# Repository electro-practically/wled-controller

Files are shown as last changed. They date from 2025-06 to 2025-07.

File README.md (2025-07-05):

# WLED Controller

**WLED Controller** is a compact, **single-sided PCB** designed to run WLED firmware and control **two addressable LED strips**. It is powered entirely via **USB-C Power-Delivery** and supports either **5V or 12V** LED strips, with a maximum power of **60W**. Compatible with popular LED types such as **WS2812B** (5V) and **WS2815** (12V). It offers a clean, efficient solution for custom lighting projects.

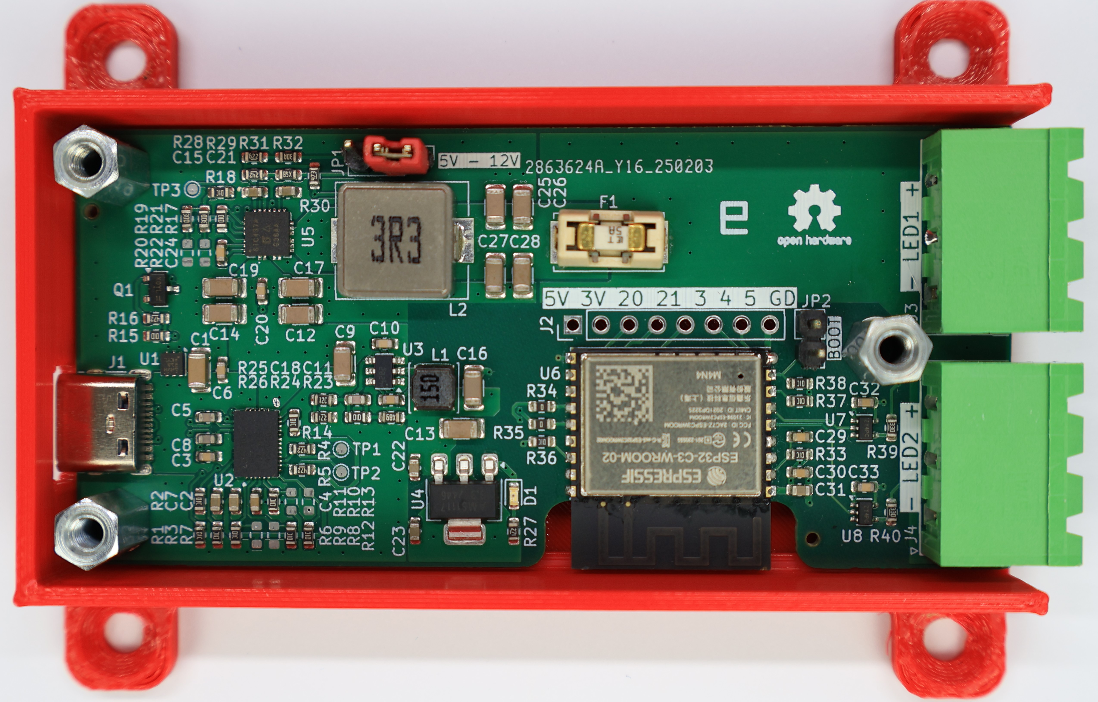
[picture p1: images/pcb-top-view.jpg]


## Block diagram



The entire board is powered via the USB-C connector. Voltage and current levels are negotiated through the TPS25730D USB Power Delivery (PD) controller, based on onboard configuration resistors. The supported input range is 5–20 V and 0.5–5 A, and the controller always negotiates the highest available voltage profile supported by the connected power adapter. These voltage/current profiles can be customized by soldering different resistor values.

There are two power paths:

1. **LED Power Path**: supplies power to the LED strips. The input voltage is stepped down by a SiC437 buck converter, providing high-efficiency regulation tailored to the selected LED voltage (5 V or 12 V). This path is protected by a fuse.

2. **Logic Power Path**: supplies power to the ESP32 and other low-power components. This path uses a TPS54202 buck converter to generate a stable 5 V rail, which is further regulated down to 3.3 V using an AMS1117 low-dropout (LDO) regulator.

A dedicated ENABLE signal from the ESP32 is used to control the LED power converter (SiC437). When LEDs are turned off in WLED, this signal disables the converter entirely - removing the need for additional output relays or transistors typically used to disconnect LED power.

The USB-C connector also provides a direct connection to the ESP32 via the USB 2.0, allowing firmware flashing and debug access without additional interfaces.

## PCB description

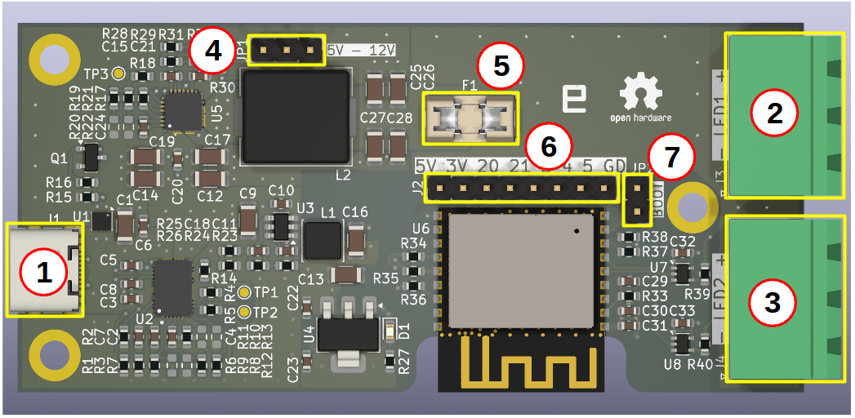
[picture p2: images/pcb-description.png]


1. **USB-C connector.** Used for flashing the WLED firmware onto the ESP32 and for powering the entire board—including connected LED strips—via the USB Power Delivery (PD) protocol. Ensure you use a high-quality USB-C cable capable of handling the required current.
2. **LED output 1.** Connector for the first LED strip, providing power (+/-) and data signals.
3. **LED output 2.** Connector for the second LED strip, providing power (+/-) and data signals.
4. **LED voltage selector.** This 3-pin jumper is used to select the output voltage for the connected LED strips - either 5V or 12V. Always short the center pin with either the 5V or 12V pin, depending on your required LED strip voltage. Be careful, if no jumper is installed, the output voltage will be extremely low (close to 0V), and the LED strips will not function properly.
5. **Protection fuse.** Protects the board from short circuits or faults originating from the connected LED strips.
6. **GPIOs.** These exposed GPIO pins can be configured in WLED to support a variety of additional functions beyond basic LED control, including buttons, I2S microphone, IR receiver etc. Pin description:
    1. +5V
    2. +3.3V
    3. GPIO20
    4. GPIO21
    5. GPIO3
    6. GPIO4
    7. GPIO5
    8. GND
7. **Boot jumper.** Used to place the ESP32 into bootloader mode for firmware flashing.

## Bring-up guide

Follow these steps to flash the WLED firmware and configure the board:

1. Set the LED voltage jumper (5 V or 12 V) according to your connected LED strips.
2. Place a jumper on the BOOT connector to put the ESP32 into bootloader mode.
3. Connect the board to your PC using a USB-C cable.
4. Once connected, remove the BOOT jumper.
5. Install the WLED firmware following the official instructions: [kno.wled.ge](https://kno.wled.ge/basics/getting-started/)
6. Configure WLED as follows (see LED Preferences settings category in the web UI):
    1. **LED1 Data GPIO**: 7
    2. **LED2 Data GPIO**: 6
    3. **Relay GPIO**: 10 (no invert, no open drain)
7. Disconnect the USB from your PC and connect a suitable power adapter via USB-C.
8. Setup complete - the board is ready to use.

## Thermal consideration

If you power a long LED strip with relatively high power consumption, it may be necessary to provide heat dissipation for the controller - for example, using an aluminum case or a case with a fan. Most of the heat is dissipated by the SiC437 buck converter.

## Input power source type

The controller was tested with a standard USB power brick used for phone charging with USB Power Delivery capability. However, it should also work with other USB-C devices that support Power Delivery in source mode - for example, power banks, monitors, laptops, and similar devices. If you plan to power the controller from such a source, ensure that it supports the required USB PD power profile.

## License

[CERN Open Hardware Licence Version 2 - Permissive](https://cern-ohl.web.cern.ch/home)

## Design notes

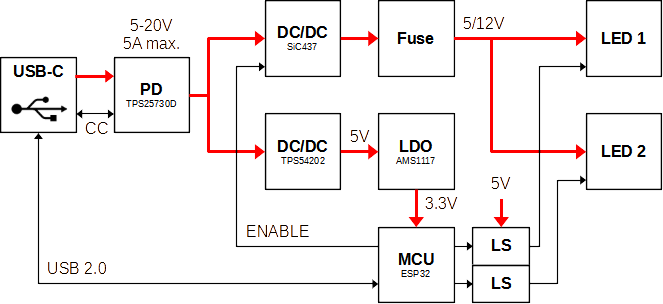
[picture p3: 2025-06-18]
images/block-diagram.png

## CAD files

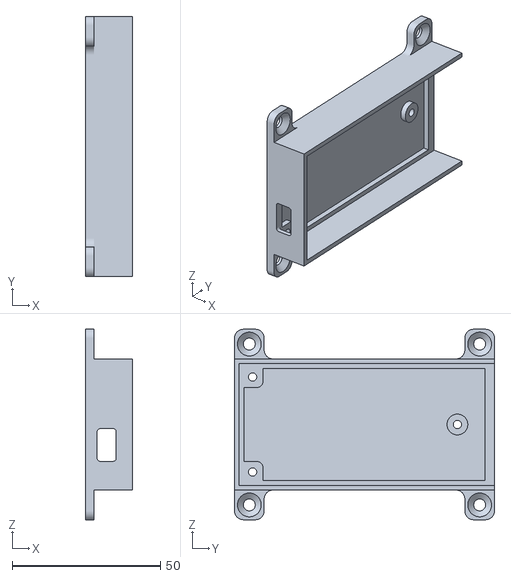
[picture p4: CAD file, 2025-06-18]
case/wled-controller-Bottom.stl
16.0 x 87.6 x 64.2

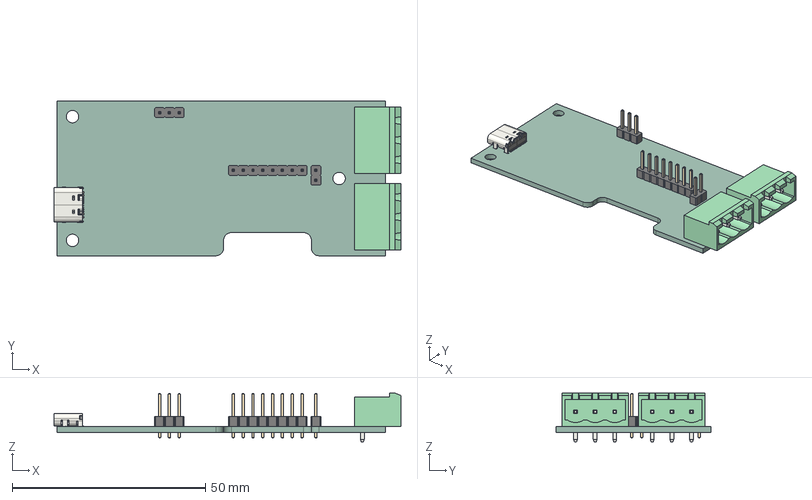
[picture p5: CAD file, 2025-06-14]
pcb/wled-controller.step
89.8 x 40.0 x 12.6 mm
PinHeader_1x03_P2.54mm_Vertical
PinHeader_1x08_P2.54mm_Vertical
PhoenixContact_MSTBA_2,5_3-G-5,08_1x03_P5.08mm_Horizontal x 2
USB_C_Receptacle_GCT_USB4105-xx-A_16P_TopMnt_Horizontal
PinHeader_1x02_P2.54mm_Vertical
wled-controller_PCB

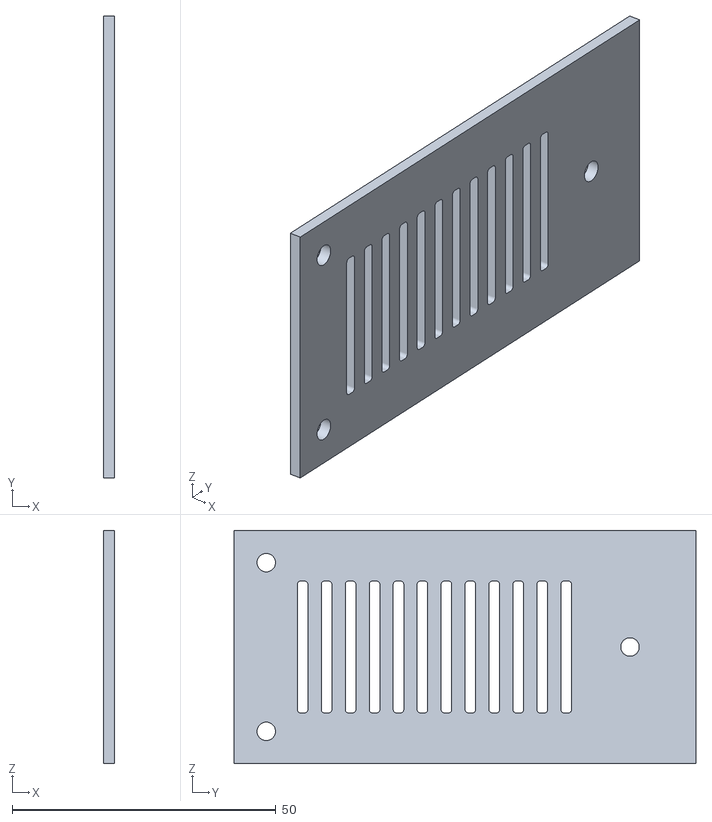
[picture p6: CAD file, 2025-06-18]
case/wled-controller-Top.stl
2.00 x 87.6 x 44.2

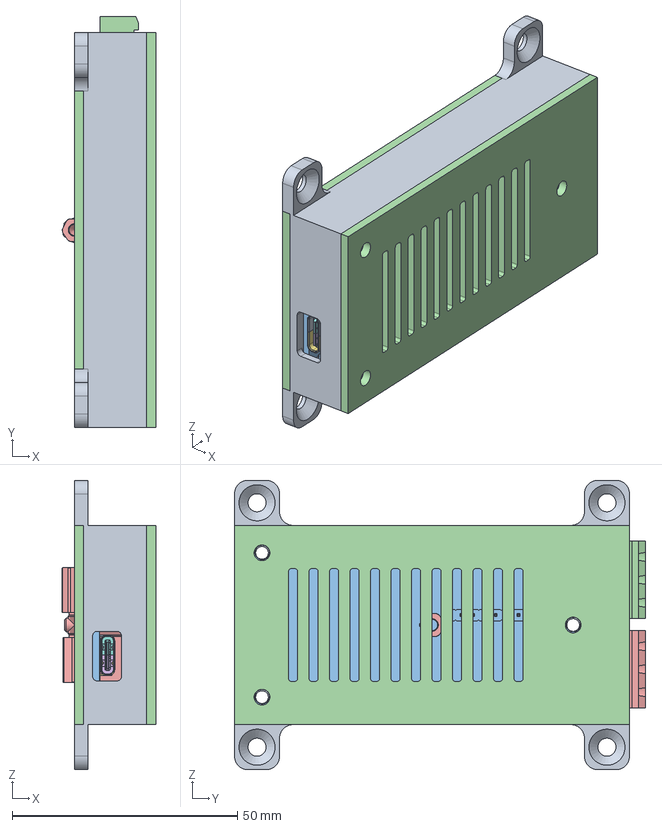
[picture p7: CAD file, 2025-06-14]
case/wled-controller.FCStd
20.7 x 91.1 x 64.2 mm
Bottom x 2
PinHeader_1x03_P2.54mm_Vertical
PinHeader_1x08_P2.54mm_Vertical
PhoenixContact_MSTBA_2,5_3-G-5,08_1x03_P5.08mm_Horizontal
PhoenixContact_MSTBA_2,5_3-G-5,08_1x03_P5.08mm_Horizontal001
USB_C_Receptacle_GCT_USB4105-xx-A_16P_TopMnt_Horizontal
USB_C_Receptacle_GCT_USB4105-xx-A_16P_TopMnt_Horizontal001
USB_C_Receptacle_GCT_USB4105-xx-A_16P_TopMnt_Horizontal002
USB_C_Receptacle_GCT_USB4105-xx-A_16P_TopMnt_Horizontal003
USB_C_Receptacle_GCT_USB4105-xx-A_16P_TopMnt_Horizontal004
USB_C_Receptacle_GCT_USB4105-xx-A_16P_TopMnt_Horizontal005
USB_C_Receptacle_GCT_USB4105-xx-A_16P_TopMnt_Horizontal006
USB_C_Receptacle_GCT_USB4105-xx-A_16P_TopMnt_Horizontal007
USB_C_Receptacle_GCT_USB4105-xx-A_16P_TopMnt_Horizontal008
USB_C_Receptacle_GCT_USB4105-xx-A_16P_TopMnt_Horizontal009
USB_C_Receptacle_GCT_USB4105-xx-A_16P_TopMnt_Horizontal010
USB_C_Receptacle_GCT_USB4105-xx-A_16P_TopMnt_Horizontal011
USB_C_Receptacle_GCT_USB4105-xx-A_16P_TopMnt_Horizontal012
USB_C_Receptacle_GCT_USB4105-xx-A_16P_TopMnt_Horizontal013
USB_C_Receptacle_GCT_USB4105-xx-A_16P_TopMnt_Horizontal014
USB_C_Receptacle_GCT_USB4105-xx-A_16P_TopMnt_Horizontal015
USB_C_Receptacle_GCT_USB4105-xx-A_16P_TopMnt_Horizontal016
USB_C_Receptacle_GCT_USB4105-xx-A_16P_TopMnt_Horizontal017
USB_C_Receptacle_GCT_USB4105-xx-A_16P_TopMnt_Horizontal018
USB_C_Receptacle_GCT_USB4105-xx-A_16P_TopMnt_Horizontal019
USB_C_Receptacle_GCT_USB4105-xx-A_16P_TopMnt_Horizontal020
USB_C_Receptacle_GCT_USB4105-xx-A_16P_TopMnt_Horizontal021
USB_C_Receptacle_GCT_USB4105-xx-A_16P_TopMnt_Horizontal022
USB_C_Receptacle_GCT_USB4105-xx-A_16P_TopMnt_Horizontal023
USB_C_Receptacle_GCT_USB4105-xx-A_16P_TopMnt_Horizontal024
USB_C_Receptacle_GCT_USB4105-xx-A_16P_TopMnt_Horizontal025
USB_C_Receptacle_GCT_USB4105-xx-A_16P_TopMnt_Horizontal026
USB_C_Receptacle_GCT_USB4105-xx-A_16P_TopMnt_Horizontal027
USB_C_Receptacle_GCT_USB4105-xx-A_16P_TopMnt_Horizontal028
USB_C_Receptacle_GCT_USB4105-xx-A_16P_TopMnt_Horizontal029
USB_C_Receptacle_GCT_USB4105-xx-A_16P_TopMnt_Horizontal030
USB_C_Receptacle_GCT_USB4105-xx-A_16P_TopMnt_Horizontal031
USB_C_Receptacle_GCT_USB4105-xx-A_16P_TopMnt_Horizontal032
USB_C_Receptacle_GCT_USB4105-xx-A_16P_TopMnt_Horizontal033
USB_C_Receptacle_GCT_USB4105-xx-A_16P_TopMnt_Horizontal034
USB_C_Receptacle_GCT_USB4105-xx-A_16P_TopMnt_Horizontal035
PinHeader_1x02_P2.54mm_Vertical
wled-controller_PCB
Top x 2
M3x10x5-Standoff x 3

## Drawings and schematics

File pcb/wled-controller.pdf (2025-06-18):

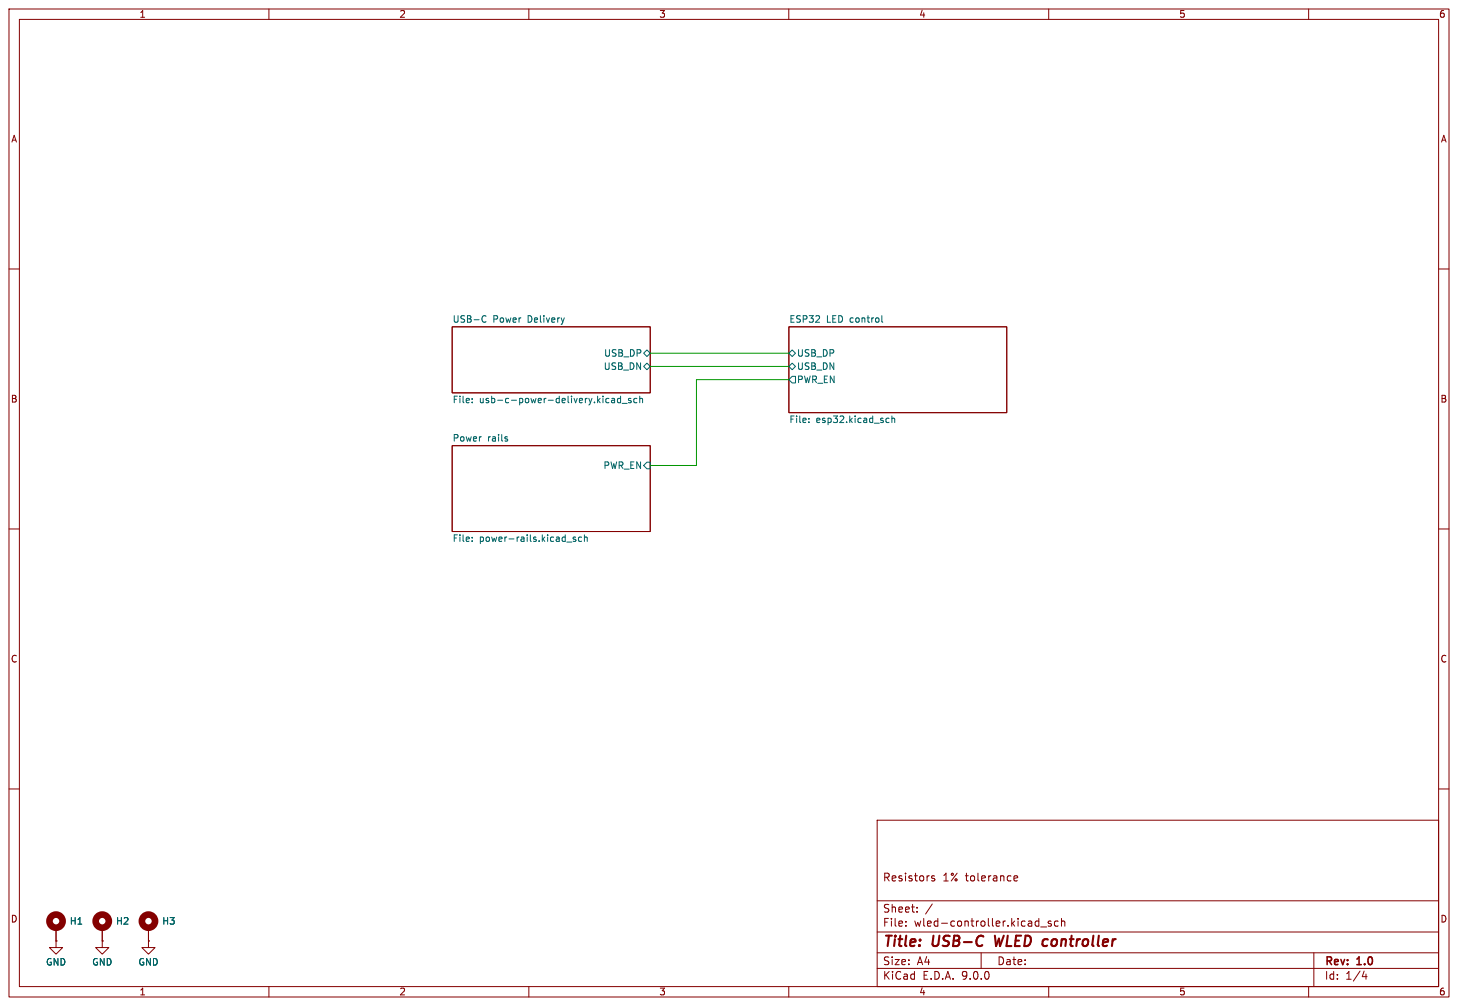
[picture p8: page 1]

Id: 1/4 Title: USB-C WLED controller File: wled-controller.kicad_sch Sheet: / Resistors 1% tolerance PWR_EN

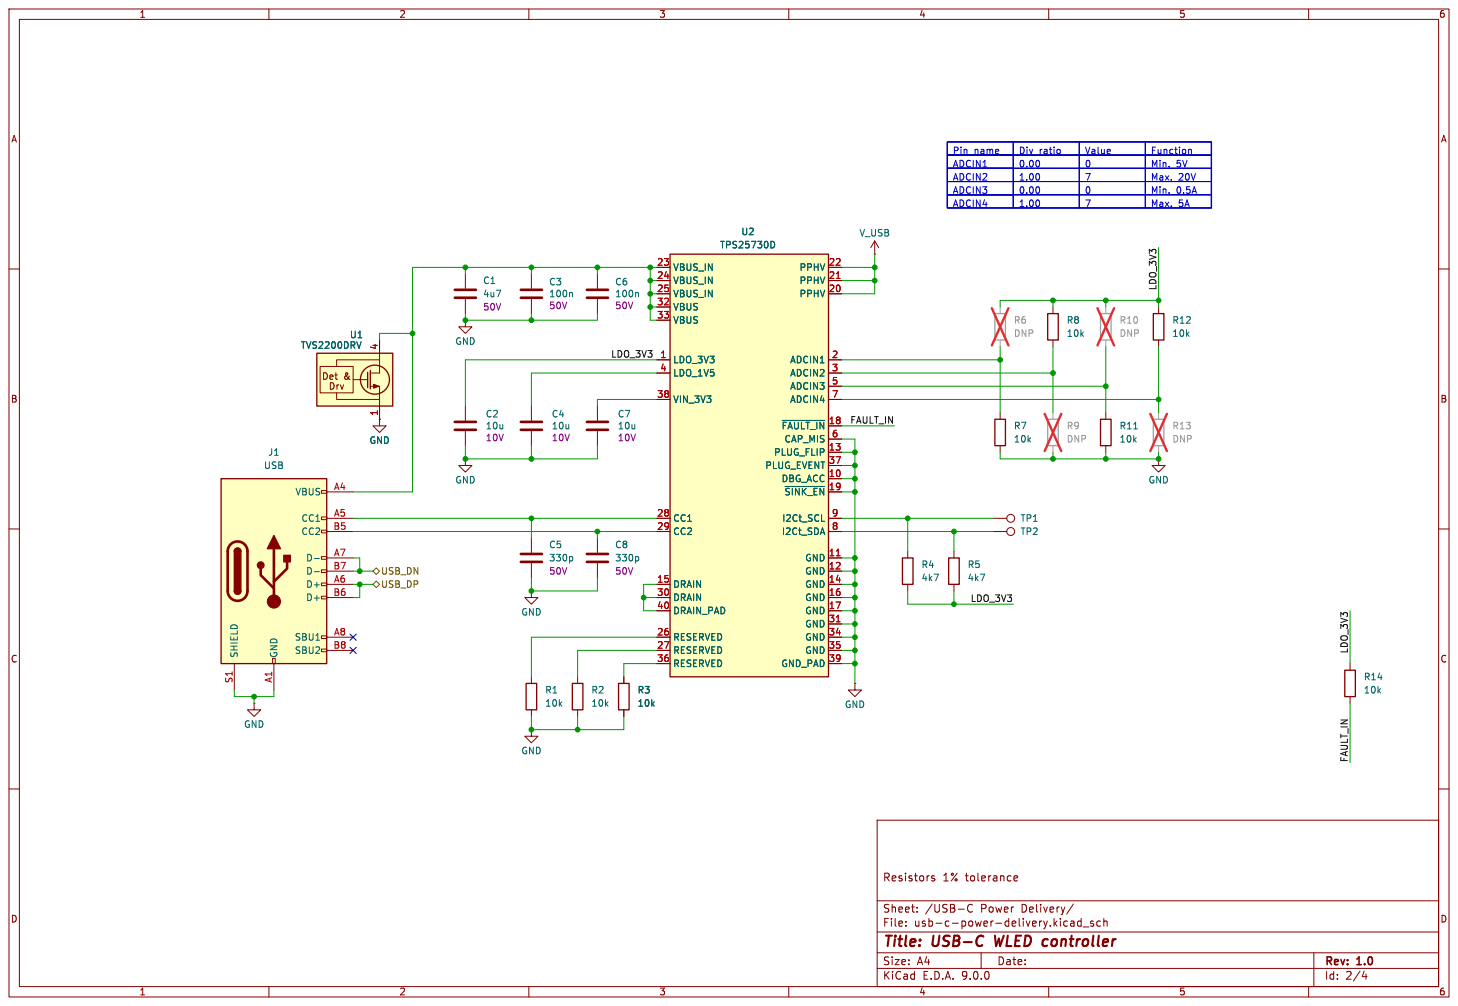
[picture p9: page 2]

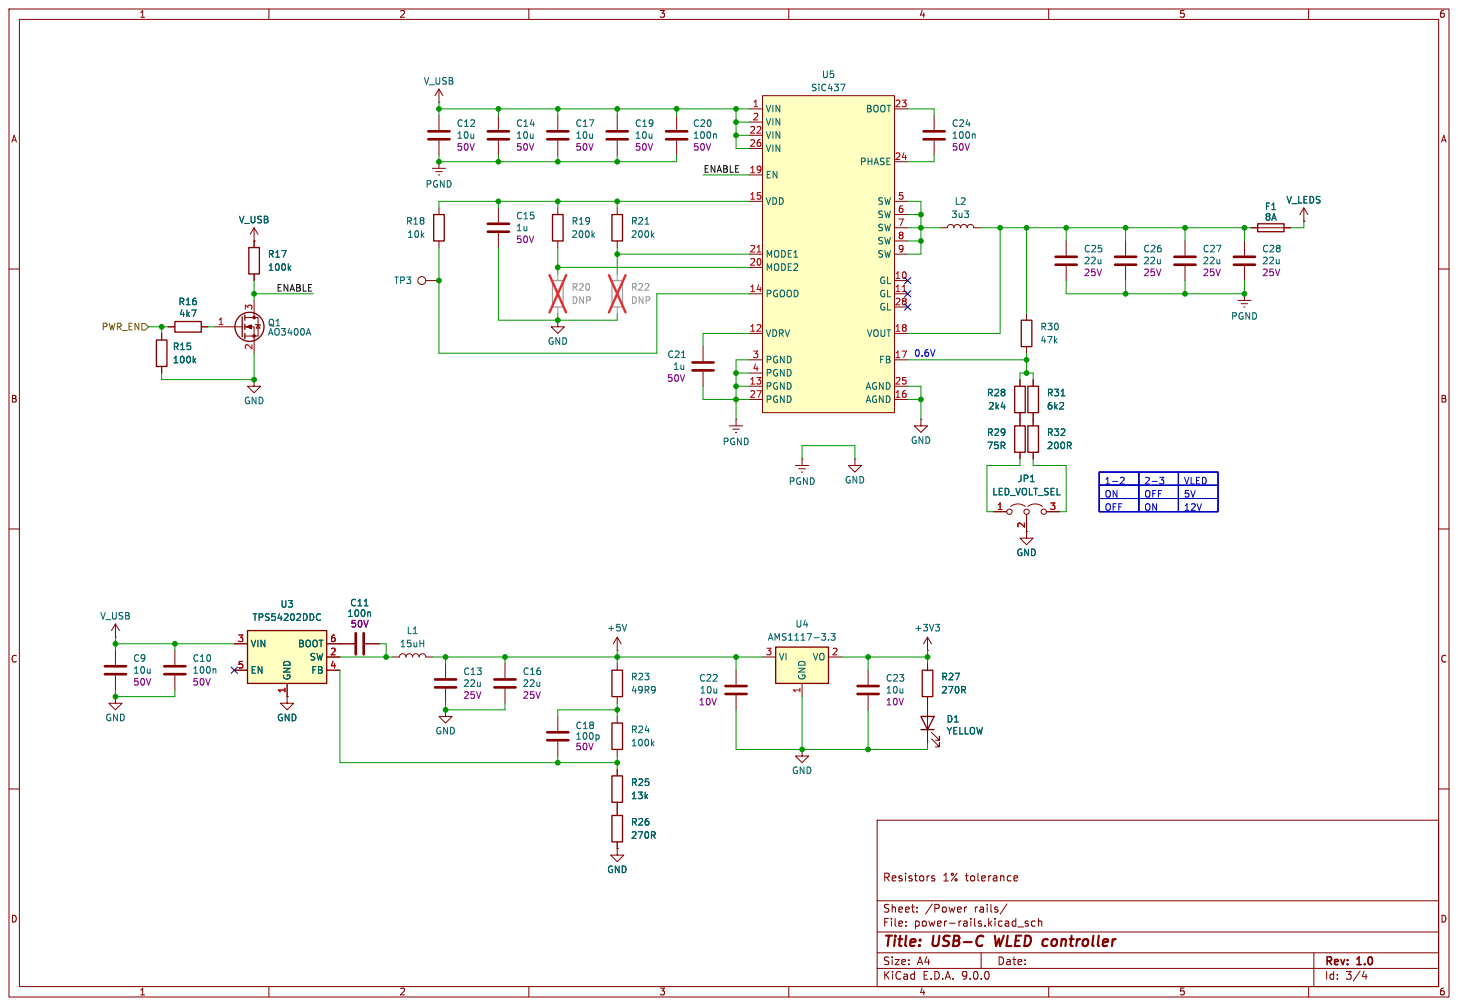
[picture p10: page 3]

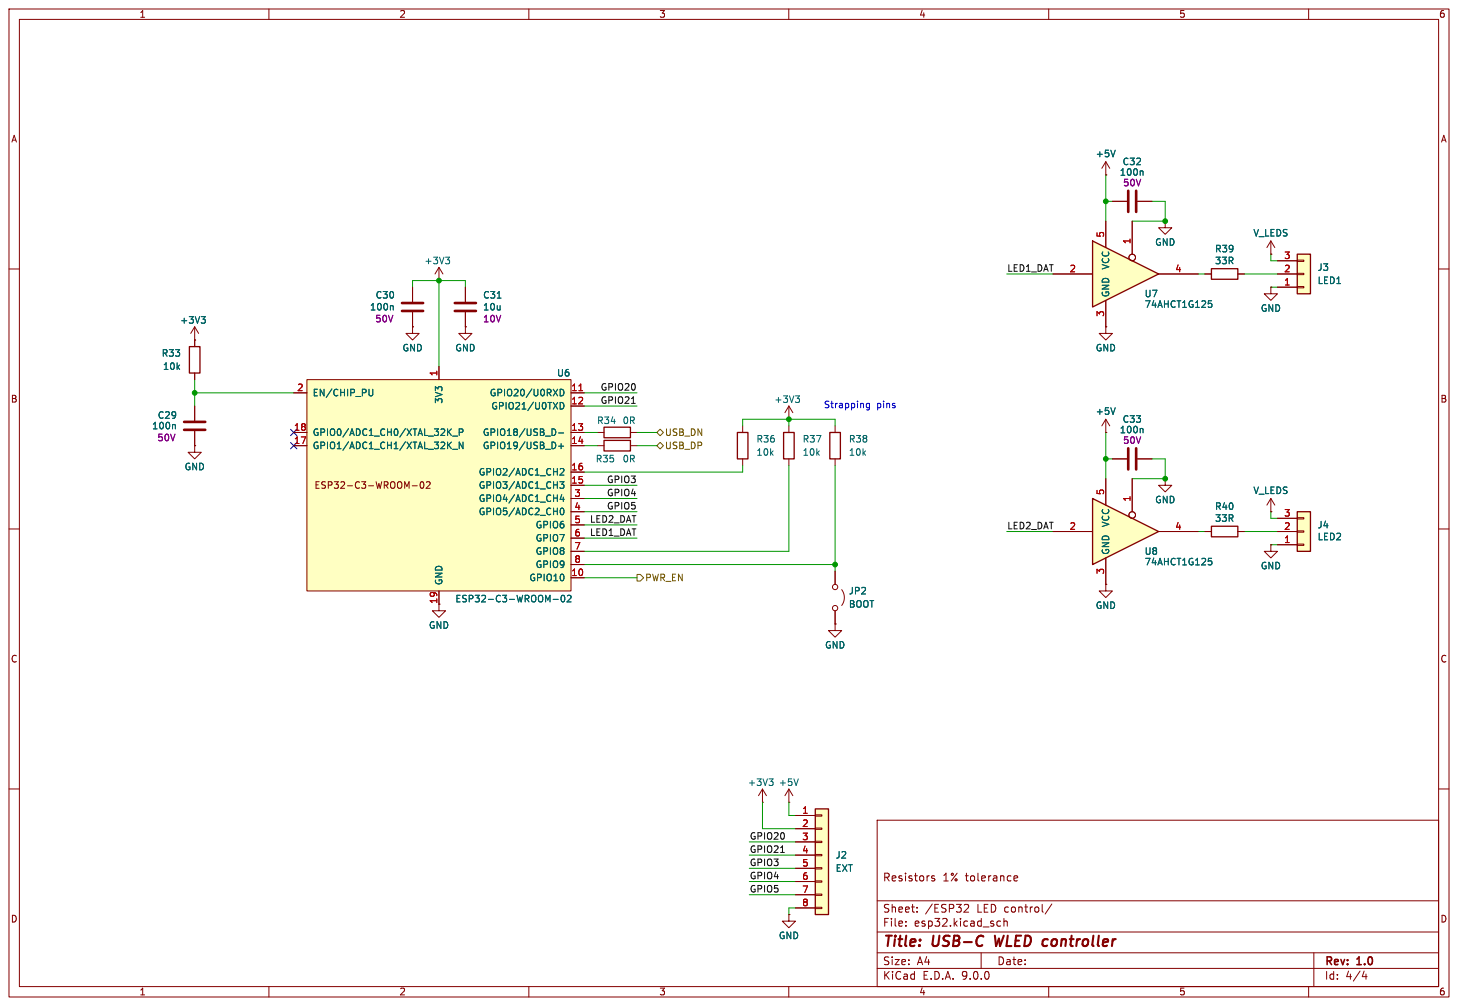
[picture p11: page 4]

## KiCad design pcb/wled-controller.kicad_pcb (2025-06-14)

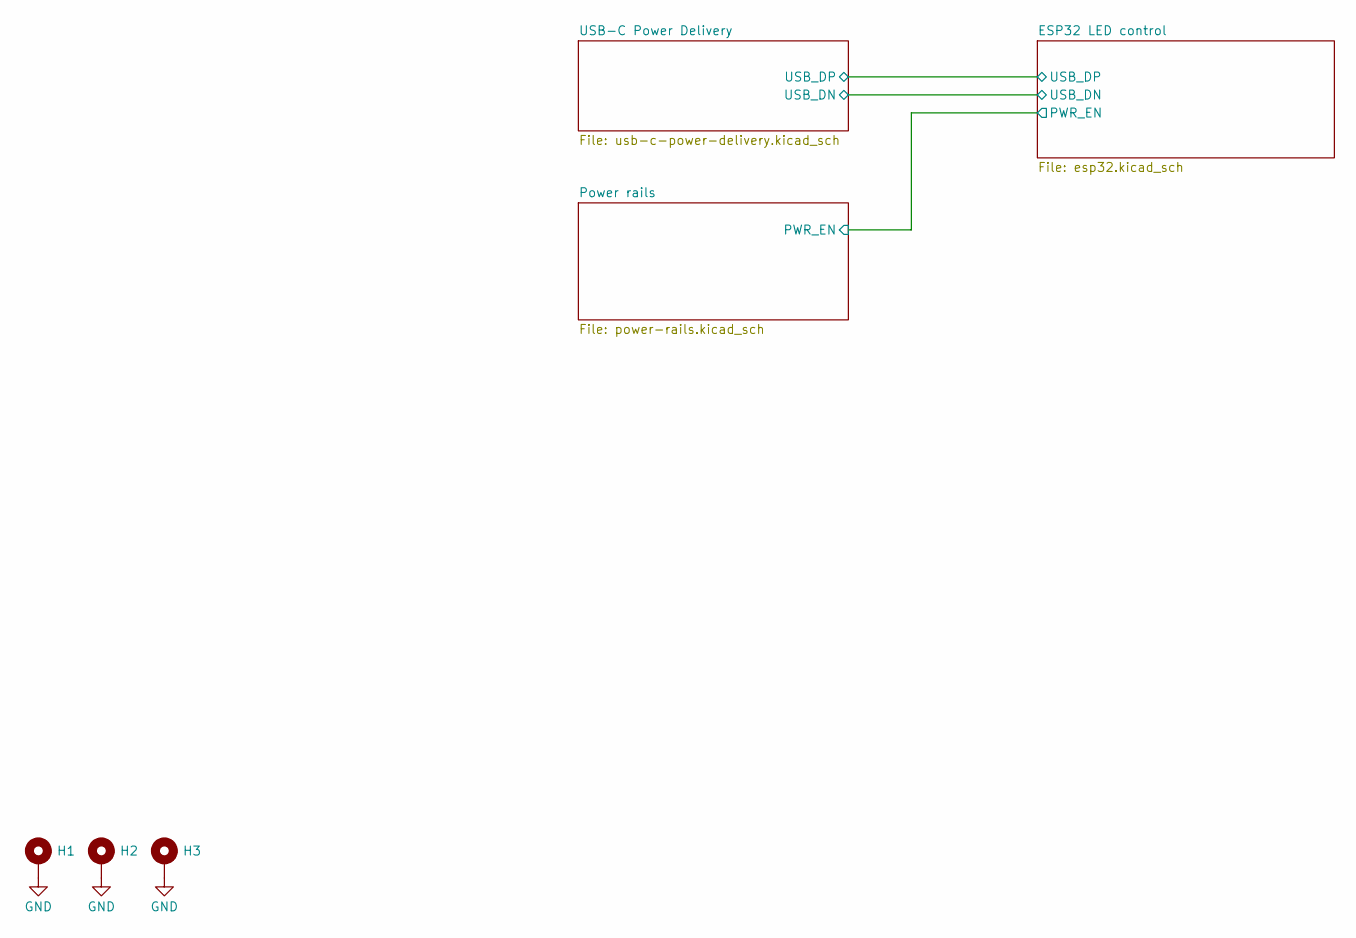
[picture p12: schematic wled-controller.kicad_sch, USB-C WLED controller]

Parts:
H1, H2, H3: MountingHole; MountingHole_3.2mm_M3_DIN965_Pad

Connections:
GND: H1.1, H2.1, H3.1; also elsewhere on the board

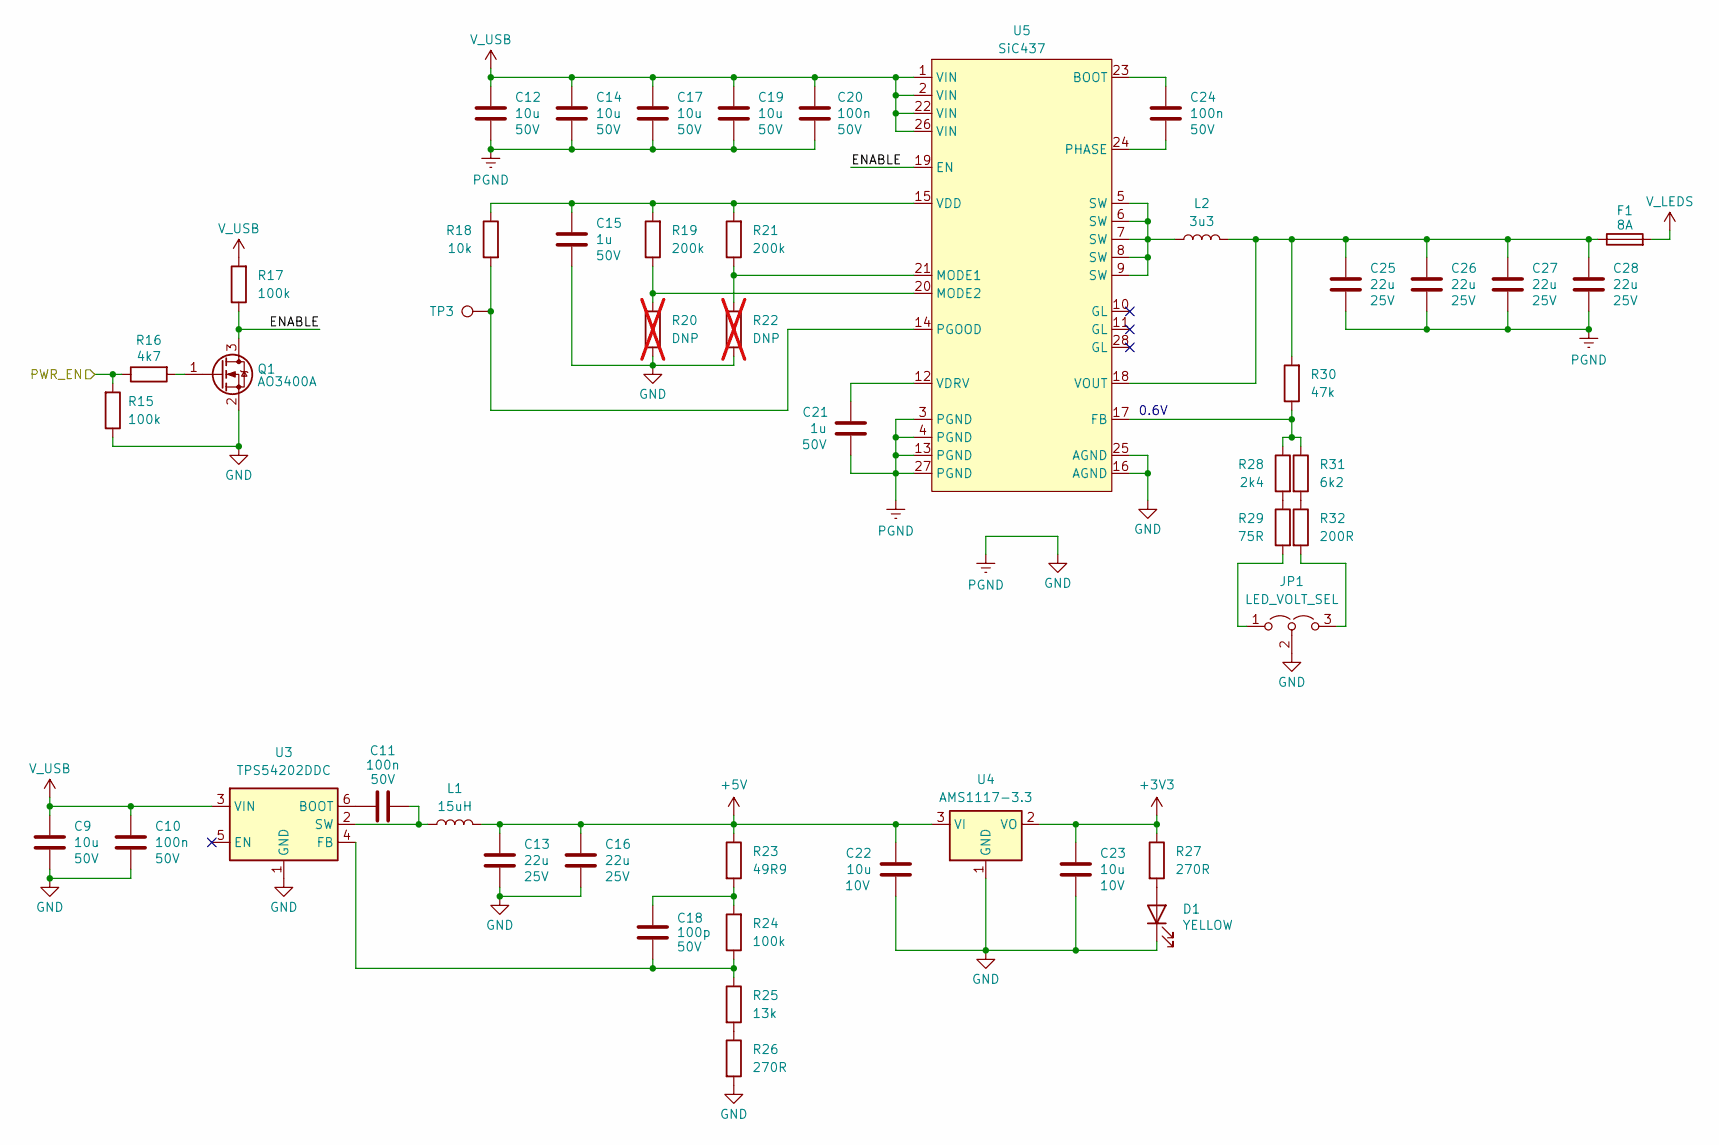
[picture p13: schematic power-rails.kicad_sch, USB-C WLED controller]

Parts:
C9, C12, C14, C17, C19: 10u; C_1206_3216Metric; Voltage 50V; JLCPCB C13585
C10, C11, C20, C24: 100n; C_0603_1608Metric; Voltage 50V; JLCPCB C14663
C13, C16, C25, C26, C27, C28: 22u; C_1206_3216Metric; Voltage 25V; JLCPCB C12891
C15, C21: 1u; C_0603_1608Metric; Voltage 50V; JLCPCB C15849
C18: 100p; C_0603_1608Metric; Voltage 50V; JLCPCB C14858
C22, C23: 10u; C_0603_1608Metric; Voltage 10V; JLCPCB C19702
D1: YELLOW; LED_0603_1608Metric; JLCPCB C72038
F1: 8A; Fuseholder_Littelfuse_Nano2_154x; JLCPCB C108518
JP1: LED_VOLT_SEL; PinHeader_1x03_P2.54mm_Vertical; JLCPCB C2937625
L1: 15uH; L_Changjiang_FNR4020S; JLCPCB C167837
L2: 3u3; L_Chilisin_BMRF00101040; JLCPCB C7587741
Q1: AO3400A; SOT-23; JLCPCB C20917
R15, R17, R24: 100k; R_0603_1608Metric; JLCPCB C25803
R16: 4k7; R_0603_1608Metric; JLCPCB C23162
R18: 10k; R_0603_1608Metric; JLCPCB C25804
R19, R21: 200k; R_0603_1608Metric; JLCPCB C25811
R20, R22: DNP; R_0603_1608Metric; not fitted
R23: 49R9; R_0603_1608Metric; JLCPCB C23185
R25: 13k; R_0603_1608Metric; JLCPCB C22797
R26, R27: 270R; R_0603_1608Metric; JLCPCB C22966
R28: 2k4; R_0603_1608Metric; JLCPCB C22940
R29: 75R; R_0603_1608Metric; JLCPCB C4275
R30: 47k; R_0603_1608Metric; JLCPCB C25819
R31: 6k2; R_0603_1608Metric; JLCPCB C4260
R32: 200R; R_0603_1608Metric; JLCPCB C8218
TP3: TESTPOINT; TestPoint_Pad_D1.0mm
U3: TPS54202DDC; SOT-23-6; JLCPCB C191884
U4: AMS1117-3.3; SOT-223-3_TabPin2; JLCPCB C6186
U5: SiC437; SIC437BEDT1GE3; JLCPCB C2071432

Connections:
+3V3: C23.1, R27.1, U4.2 (VO); also elsewhere on the board
+5V: C13.1, C16.1, C22.1, L1.2, R23.1, U4.3 (VI); also elsewhere on the board
/ESP32 LED control/PWR_EN: R15.2, R16.1; also elsewhere on the board
/Power rails/ENABLE: Q1.3 (D), R17.1, U5.19 (EN)
GND: C9.2, C10.1, C12.2, C13.2, C14.2, C15.1, C16.2, C17.2, C19.2, C20.2, C21.1, C22.2, C23.2, C25.2, C26.2, C27.2, C28.2, D1.1 (K), JP1.2 (C), Q1.2 (S), R15.1, R20.1, R22.1, R26.2, U3.1 (GND), U4.1 (GND), U5.3 (PGND), U5.4 (PGND), U5.13 (PGND), U5.16 (AGND), U5.25 (AGND), U5.27 (PGND); also elsewhere on the board
unnamed: C18.1, R23.2, R24.2
unnamed: D1.2 (A), R27.2
unnamed: JP1.1 (A), R29.2
unnamed: JP1.3 (B), R32.2
unnamed: L2.1, U5.5 (SW), U5.6 (SW), U5.7 (SW), U5.8 (SW), U5.9 (SW)
unnamed: Q1.1 (G), R16.2
unnamed: R25.2, R26.1
unnamed: R28.2, R29.1
unnamed: R31.2, R32.1
unnamed: C11.2, U3.6 (BOOT)
unnamed: C18.2, R24.1, R25.1, U3.4 (FB)
unnamed: C11.1, L1.1, U3.2 (SW)
unnamed: C24.2, U5.23 (BOOT)
unnamed: R28.1, R30.1, R31.1, U5.17 (FB)
unnamed: R21.1, R22.2, U5.21 (MODE1)
unnamed: R19.1, R20.2, U5.20 (MODE2)
unnamed: R18.2, TP3.1, U5.14 (PGOOD)
unnamed: C24.1, U5.24 (PHASE)
unnamed: C15.2, R18.1, R19.2, R21.2, U5.15 (VDD)
unnamed: C21.2, U5.12 (VDRV)
unnamed: C25.1, C26.1, C27.1, C28.1, F1.1, L2.2, R30.2, U5.18 (VOUT)
V_LEDS: F1.2; also elsewhere on the board
V_USB: C9.1, C10.2, C12.1, C14.1, C17.1, C19.1, C20.1, R17.2, U3.3 (VIN), U5.1 (VIN), U5.2 (VIN), U5.22 (VIN), U5.26 (VIN); also elsewhere on the board

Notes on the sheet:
0.6V

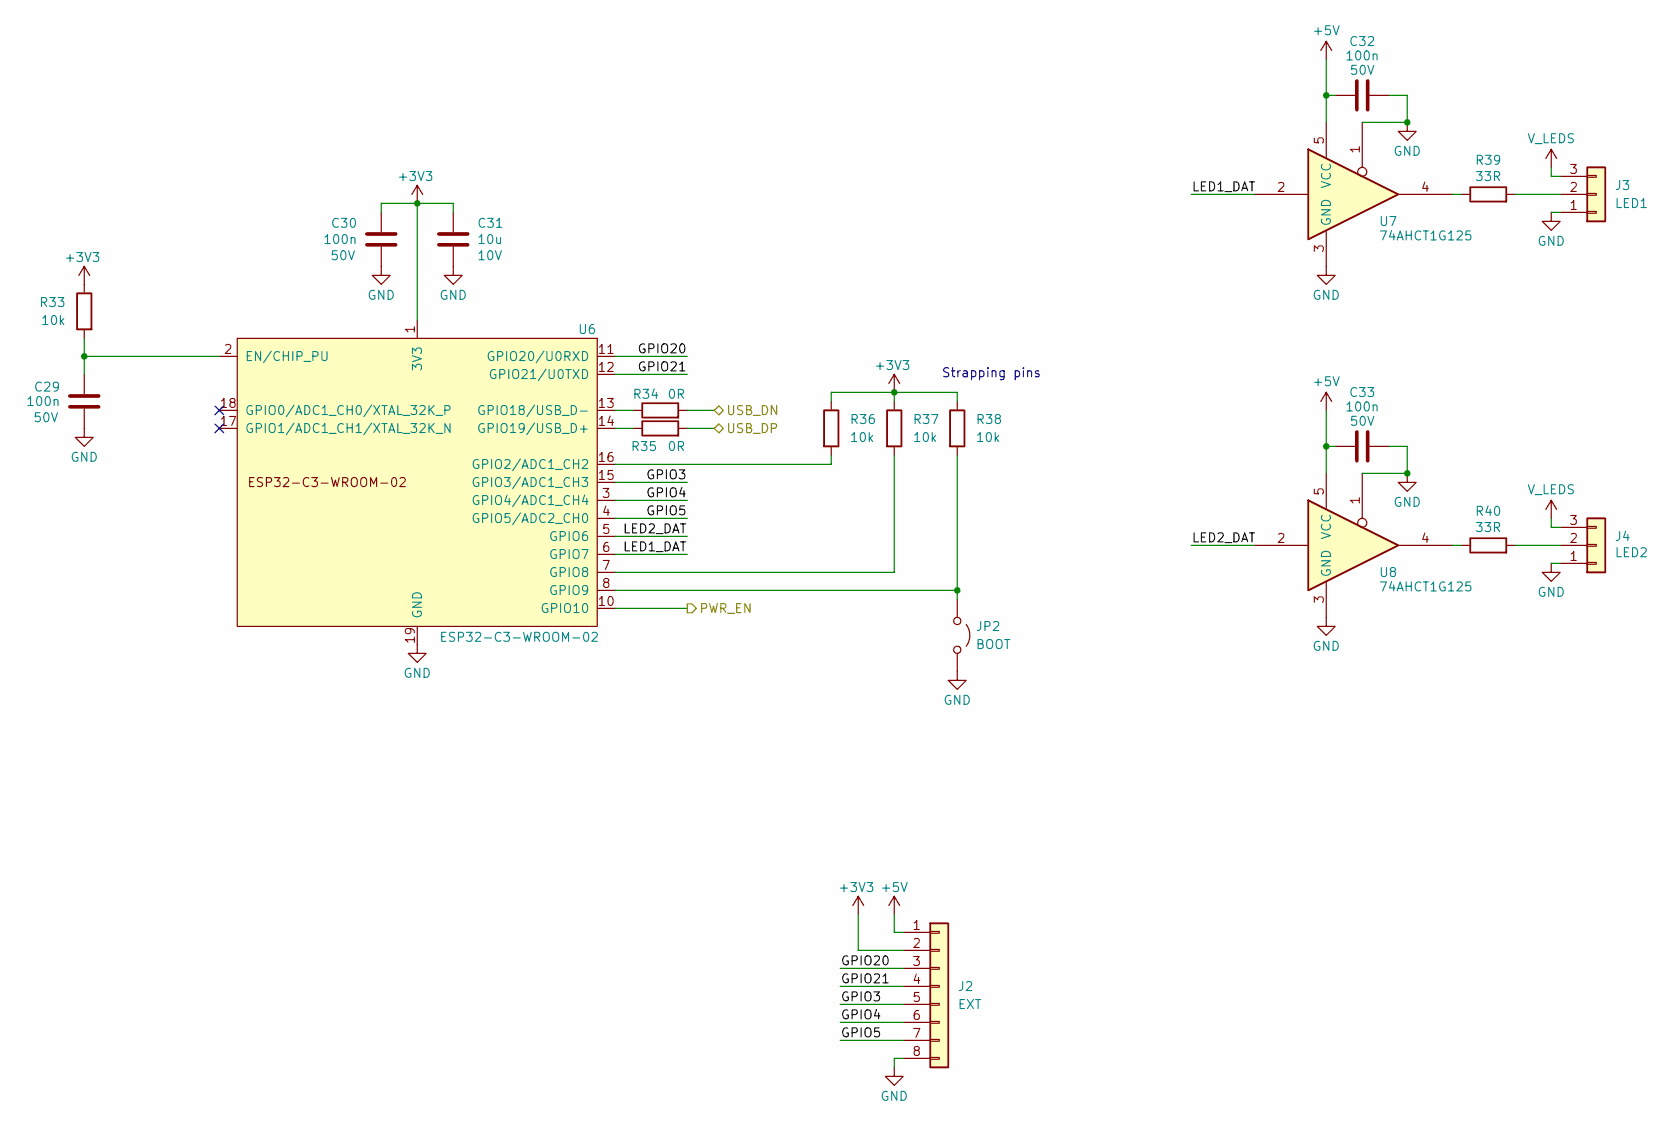
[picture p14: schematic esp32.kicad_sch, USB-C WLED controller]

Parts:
C29, C30, C32, C33: 100n; C_0603_1608Metric; Voltage 50V; JLCPCB C14663
C31: 10u; C_0603_1608Metric; Voltage 10V; JLCPCB C19702
J2: EXT; PinHeader_1x08_P2.54mm_Vertical
J3: LED1; PhoenixContact_MSTBA_2,5_3-G-5,08_1x03_P5.08mm_Horizontal; JLCPCB C8377
J4: LED2; PhoenixContact_MSTBA_2,5_3-G-5,08_1x03_P5.08mm_Horizontal; JLCPCB C8377
JP2: BOOT; PinHeader_1x02_P2.54mm_Vertical; JLCPCB C492401
R33, R36, R37, R38: 10k; R_0603_1608Metric; JLCPCB C25804
R34, R35: 0R; R_0603_1608Metric; JLCPCB C23162
R39, R40: 33R; R_0603_1608Metric; JLCPCB C23140
U6: ESP32-C3-WROOM-02; JLCPCB C2934560
U7, U8: 74AHCT1G125; SOT-353_SC-70-5; JLCPCB C151417

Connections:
+3V3: C30.1, C31.1, J2.2, R33.1, R36.1, R37.1, R38.1, U6.1 (3V3); also elsewhere on the board
+5V: C32.1, C33.1, J2.1, U7.5 (VCC), U8.5 (VCC); also elsewhere on the board
/ESP32 LED control/GPIO3: J2.5, U6.15 (GPIO3/ADC1_CH3)
/ESP32 LED control/GPIO4: J2.6, U6.3 (GPIO4/ADC1_CH4)
/ESP32 LED control/GPIO5: J2.7, U6.4 (GPIO5/ADC2_CH0)
/ESP32 LED control/GPIO20: J2.3, U6.11 (GPIO20/U0RXD)
/ESP32 LED control/GPIO21: J2.4, U6.12 (GPIO21/U0TXD)
/ESP32 LED control/LED1_DAT: U6.6 (GPIO7), U7.2
/ESP32 LED control/LED2_DAT: U6.5 (GPIO6), U8.2
/ESP32 LED control/PWR_EN: U6.10 (GPIO10); also elsewhere on the board
/ESP32 LED control/USB_DN: R34.2; also elsewhere on the board
/ESP32 LED control/USB_DP: R35.2; also elsewhere on the board
GND: C29.2, C30.2, C31.2, C32.2, C33.2, J2.8, J3.1, J4.1, JP2.2 (B), U6.9 (GND), U6.19 (GND), U7.1, U7.3 (GND), U8.1, U8.3 (GND); also elsewhere on the board
unnamed: J3.2, R39.2
unnamed: J4.2, R40.2
unnamed: JP2.1 (A), R38.2, U6.8 (GPIO9)
unnamed: R39.1, U7.4
unnamed: R40.1, U8.4
unnamed: C29.1, R33.2, U6.2 (EN/CHIP_PU)
unnamed: R36.2, U6.16 (GPIO2/ADC1_CH2)
unnamed: R37.2, U6.7 (GPIO8)
unnamed: R34.1, U6.13 (GPIO18/USB_D-)
unnamed: R35.1, U6.14 (GPIO19/USB_D+)
V_LEDS: J3.3, J4.3; also elsewhere on the board

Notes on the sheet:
Strapping pins

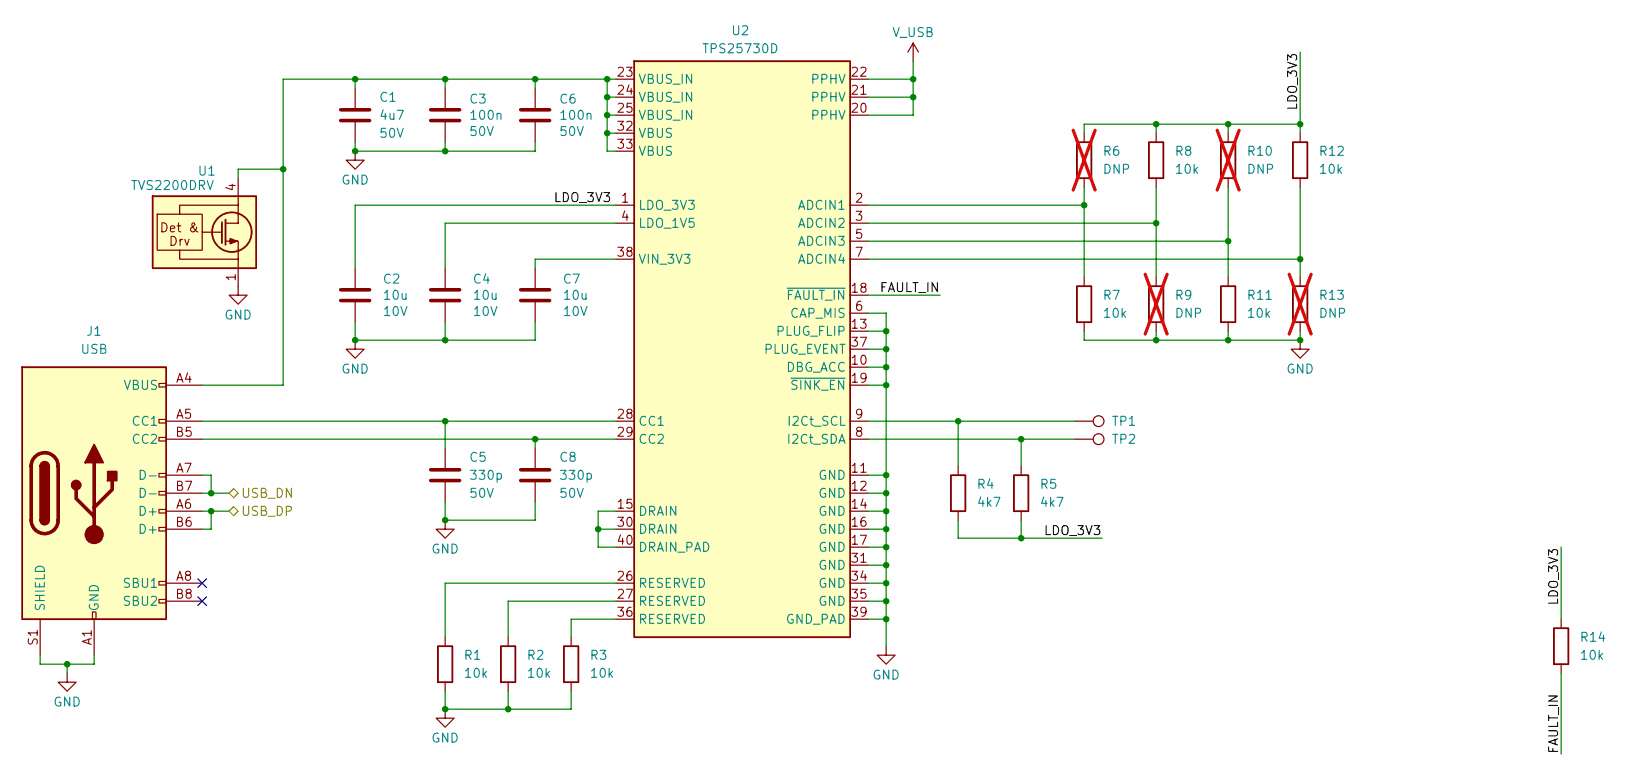
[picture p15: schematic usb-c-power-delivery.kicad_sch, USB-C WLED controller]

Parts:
C1: 4u7; C_1206_3216Metric; Voltage 50V; JLCPCB C29823
C2, C4, C7: 10u; C_0603_1608Metric; Voltage 10V; JLCPCB C19702
C3, C6: 100n; C_0603_1608Metric; Voltage 50V; JLCPCB C14663
C5, C8: 330p; C_0603_1608Metric; Voltage 50V; JLCPCB C1664
J1: USB; USB_C_Receptacle_XKB_U262-16XN-4BVC11; JLCPCB C165948
R1, R2, R3, R7, R8, R11, R12, R14: 10k; R_0603_1608Metric; JLCPCB C25804
R4, R5: 4k7; R_0603_1608Metric; JLCPCB C23162
R6, R9, R10, R13: DNP; R_0603_1608Metric; not fitted
TP1, TP2: TESTPOINT; TestPoint_Pad_D1.0mm
U1: TVS2200DRV; WSON-6-1EP_2x2mm_P0.65mm_EP1x1.6mm; JLCPCB C523793
U2: TPS25730D; IC_TPS25750DRJKR; JLCPCB C22438973

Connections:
/ESP32 LED control/USB_DN: J1.A7 (D-), J1.B7 (D-); also elsewhere on the board
/ESP32 LED control/USB_DP: J1.A6 (D+), J1.B6 (D+); also elsewhere on the board
/USB-C Power Delivery/FAULT_IN: R14.2, U2.18 (~FAULT_IN)
/USB-C Power Delivery/LDO_3V3: C2.1, R4.2, R5.2, R6.1, R8.1, R10.1, R12.1, R14.1, U2.1 (LDO_3V3)
GND: C1.2, C2.2, C3.2, C4.2, C5.2, C6.2, C7.2, C8.2, J1.A1 (GND), J1.A12 (GND), J1.B1 (GND), J1.B12 (GND), J1.S1 (SHIELD), R1.2, R2.2, R3.2, R7.2, R9.2, R11.2, R13.2, U1.1 (GND), U1.2 (GND), U1.3 (GND), U1.7 (GND), U2.6 (CAP_MIS), U2.10 (DBG_ACC), U2.11 (GND), U2.12 (GND), U2.13 (PLUG_FLIP), U2.14 (GND), U2.16 (GND), U2.17 (GND), U2.19 (~SINK_EN), U2.31 (GND), U2.34 (GND), U2.35 (GND), U2.37 (PLUG_EVENT), U2.39 (GND_PAD); also elsewhere on the board
unnamed: C1.1, C3.1, C6.1, J1.A4 (VBUS), J1.A9 (VBUS), J1.B4 (VBUS), J1.B9 (VBUS), U1.4 (IN), U1.5 (IN), U1.6 (IN), U2.23 (VBUS_IN), U2.24 (VBUS_IN), U2.25 (VBUS_IN), U2.32 (VBUS), U2.33 (VBUS)
unnamed: C5.1, J1.A5 (CC1), U2.28 (CC1)
unnamed: C8.1, J1.B5 (CC2), U2.29 (CC2)
unnamed: R1.1, U2.26 (RESERVED)
unnamed: R2.1, U2.27 (RESERVED)
unnamed: R3.1, U2.36 (RESERVED)
unnamed: R6.2, R7.1, U2.2 (ADCIN1)
unnamed: R8.2, R9.1, U2.3 (ADCIN2)
unnamed: R10.2, R11.1, U2.5 (ADCIN3)
unnamed: R12.2, R13.1, U2.7 (ADCIN4)
unnamed: U2.15 (DRAIN), U2.30 (DRAIN), U2.40 (DRAIN_PAD)
unnamed: R4.1, TP1.1, U2.9 (I2Ct_SCL)
unnamed: R5.1, TP2.1, U2.8 (I2Ct_SDA)
unnamed: C4.1, U2.4 (LDO_1V5)
unnamed: C7.1, U2.38 (VIN_3V3)
V_USB: U2.20 (PPHV), U2.21 (PPHV), U2.22 (PPHV); also elsewhere on the board

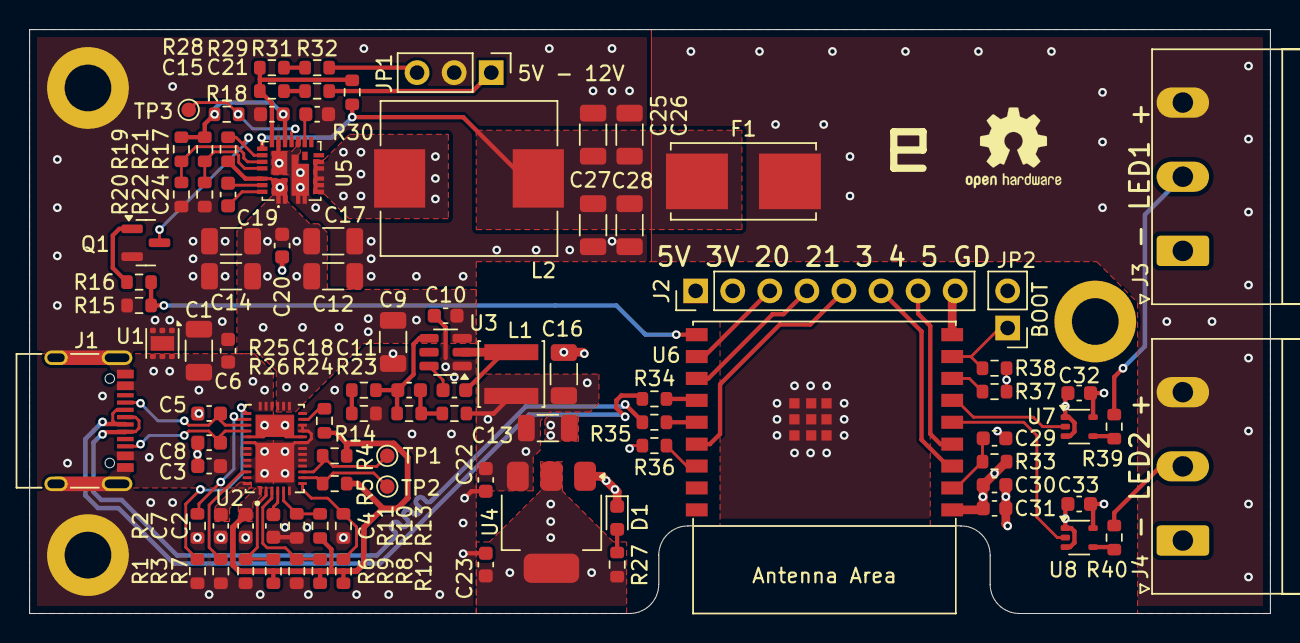
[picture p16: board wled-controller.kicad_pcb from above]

Board: 4 copper layers, 85.0 x 40.0 mm, 98 parts (0 on the bottom side), 64 nets.

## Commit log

2025-06-14 Add project files
    [esp32.kicad_sch, power-rails.kicad_sch, usb-c-power-delivery.kicad_sch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]
2025-06-15 Move PCB files to the parent directory
    [esp32.kicad_sch, power-rails.kicad_sch, usb-c-power-delivery.kicad_sch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]
2025-06-18 Add case STL files for 3D printing
    [wled-controller-Bottom.stl, wled-controller-Top.stl]
2025-06-18 Add schematic as PDF.
